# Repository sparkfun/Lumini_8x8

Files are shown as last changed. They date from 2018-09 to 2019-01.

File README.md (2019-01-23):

SparkFun LuMini 8x8 Matrix
========================================

LuMini 8x8

[*SparkFun LuMini LED matrix (COM-15047)*](https://www.sparkfun.com/products/15047)

The LuMini 8x8 Matrix is a great way to add a square of light to just about anything, or even make a screen of a custom shape. The LuMini product line uses the same LED used on our Lumenati boards, the APA102, just in a smaller, 2.0x2.0 mm package. This allows for incredibly tight pixel densities, and thus, a screen with less pixelation. 

Repository Contents
-------------------

* **/Firmware** - Example code 
* **/Hardware** - Eagle design files (.brd, .sch)
* **/Production** - Production panel files (.brd)

Documentation
--------------
* **[Hookup Guide](https://learn.sparkfun.com/tutorials/lumini-8x8-matrix-hookup-guide)** - Basic hookup guide for the LuMini 8x8 LED Matrix.

Product Versions
----------------
* [COM-15047](https://www.sparkfun.com/products/15047)- 8x8 matrix of APA102 LED's packed into a single square inch.

License Information
-------------------

This product is _**open source**_! 

Please review the LICENSE.md file for license information. 

If you have any questions or concerns on licensing, please contact techsupport@sparkfun.com.

Distributed as-is; no warranty is given.

- Your friends at SparkFun.

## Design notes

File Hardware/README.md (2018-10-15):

SparkFun <PRODUCT NAME> Design Files
=====================================

The .sch and .brd files hare are Eagle CAD schematic and PCB design files from SparkFun Electronics.
A freeware version of Eagle can be found [here](http://www.cadsoftusa.com/download-eagle/freeware/).

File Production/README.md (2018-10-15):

SparkFun <PRODUCT NAME> Production Files
=========================================

These are the production files SparkFun uses for printing PCBs.

License Information
-------------------
This product is open source! 

The hardware is released under [Creative Commons ShareAlike 4.0 International](https://creativecommons.org/licenses/by-sa/4.0/).

Please use, reuse, and modify these files as you see fit. Please maintain attribution to SparkFun Electronics and release anything derivative under the same license.

Distributed as-is; no warranty is given.

- Your friends at SparkFun.

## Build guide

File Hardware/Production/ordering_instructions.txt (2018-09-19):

panel size, 91x91mm
PCB thickness, 1.6mm
number of layers, 2
soldermask color, Unknown
silkscreen color, White
oz copper, 1oz
finish, HASL lead free
stencils, top
pcs per panel, 9

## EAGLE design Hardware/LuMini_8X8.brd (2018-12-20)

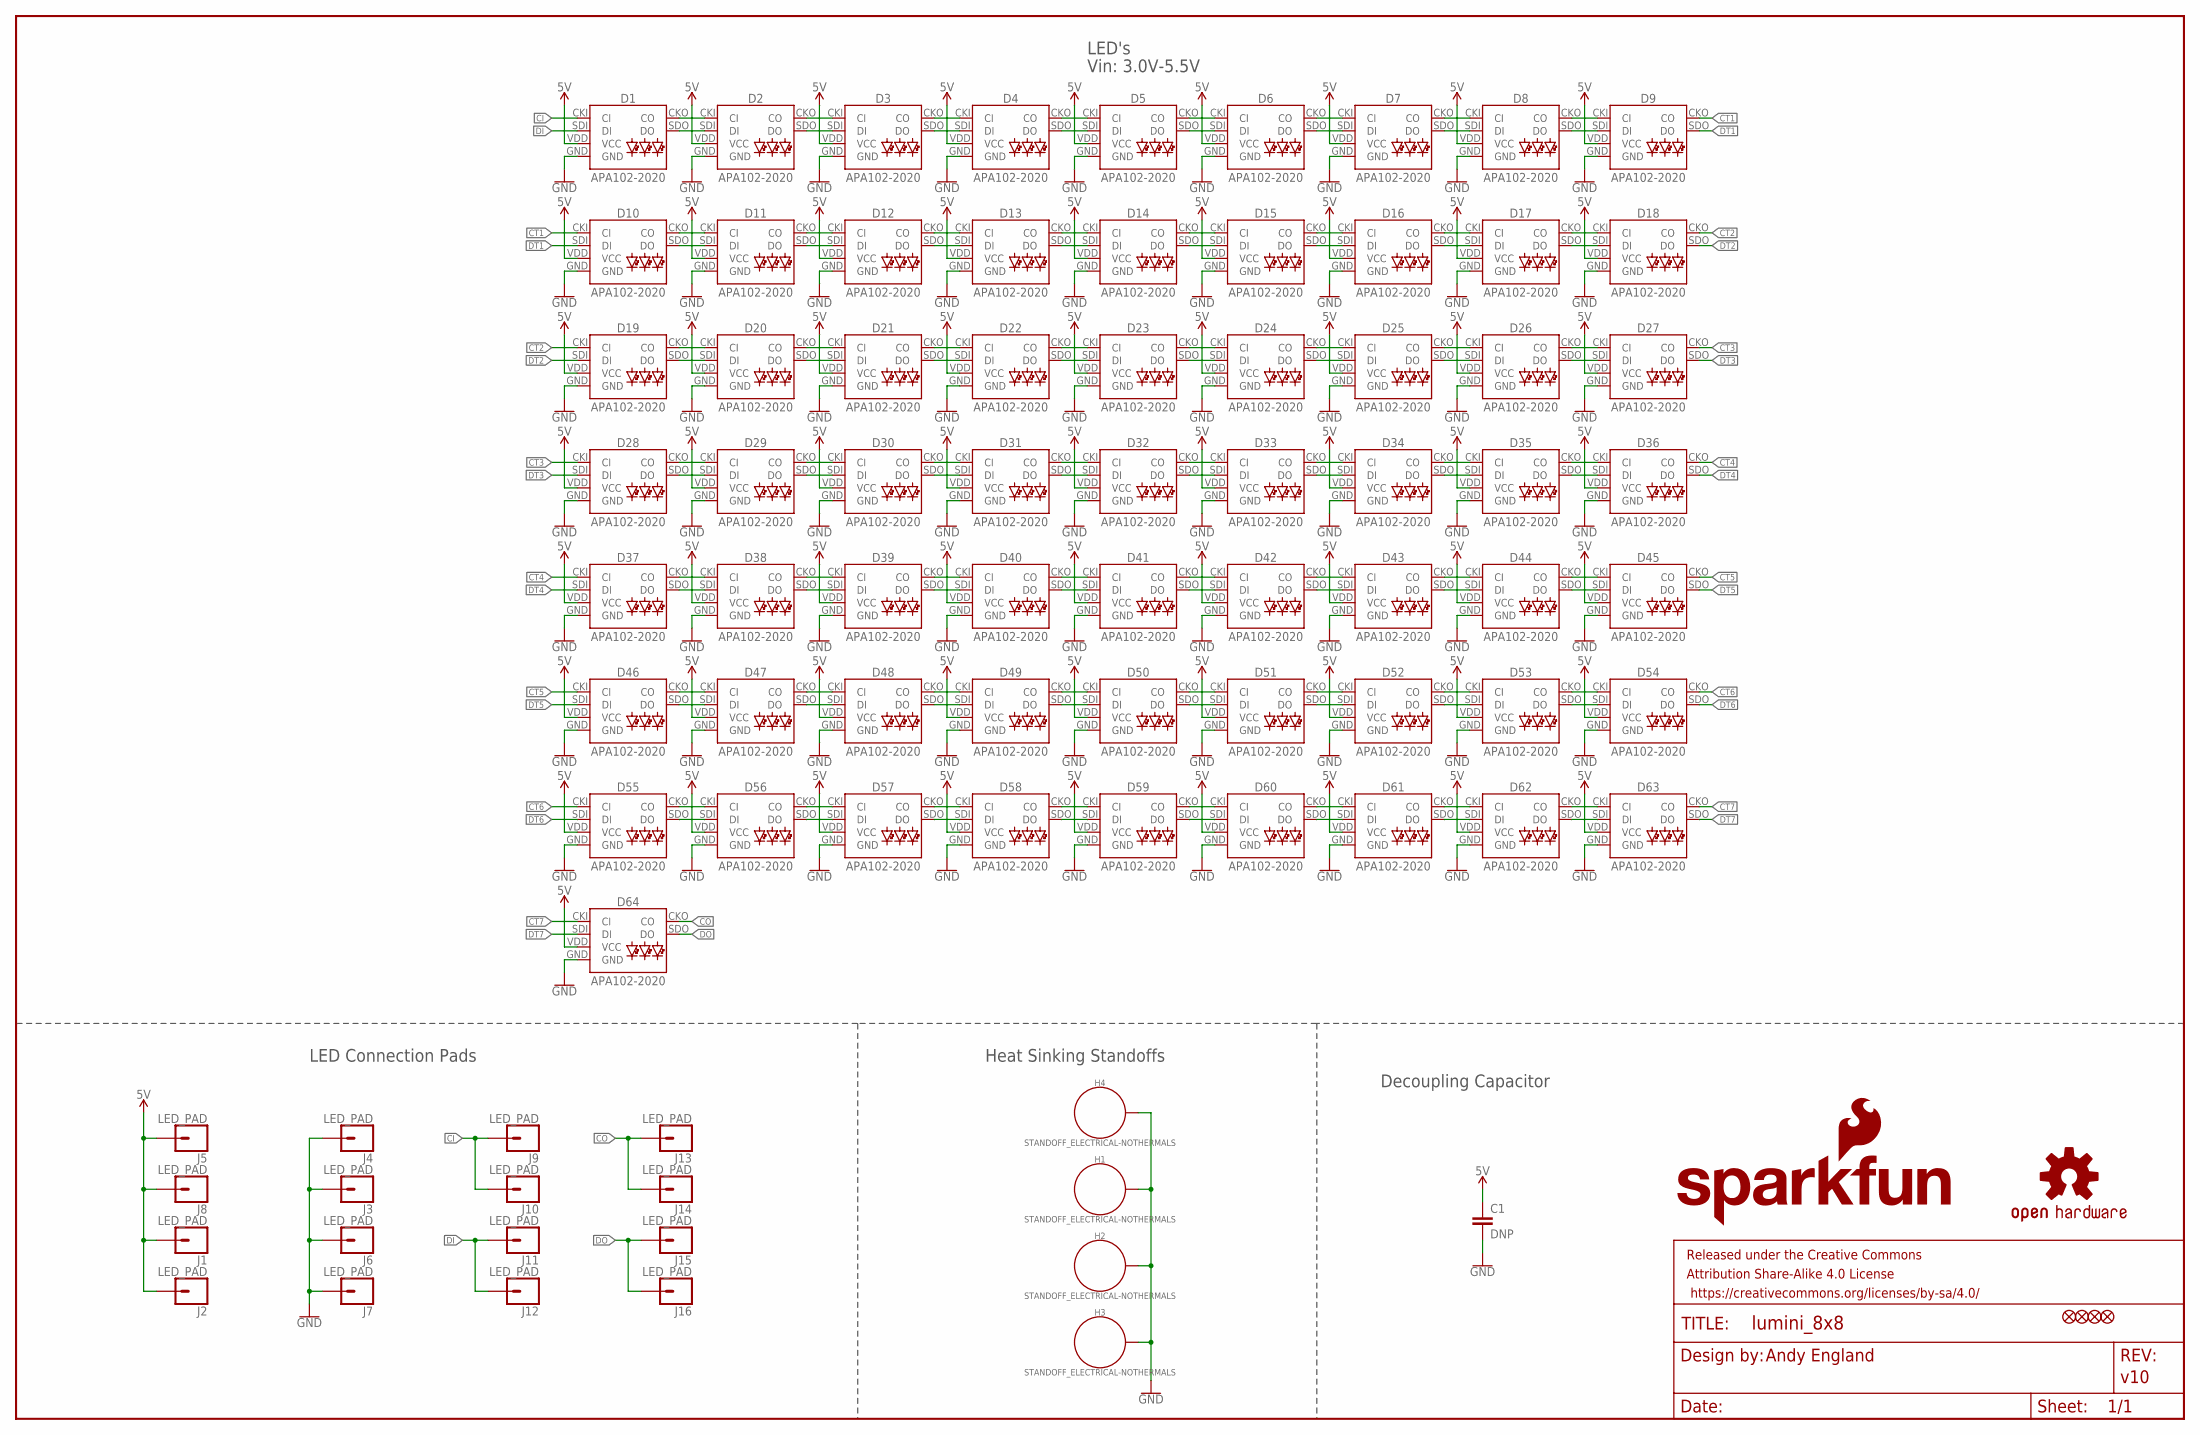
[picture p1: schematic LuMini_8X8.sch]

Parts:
C1: DNP; 1206
D1, D2, D3, D4, D5, D6, D7, D8, D9, D10, D11, D12, D13, D14, D15, D16, D17, D18, D19, D20, D21, D22, D23, D24, D25, D26, D27, D28, D29, D30, D31, D32, D33, D34, D35, D36, D37, D38, D39, D40, D41, D42, D43, D44, D45, D46, D47, D48, D49, D50, D51, D52, D53, D54, D55, D56, D57, D58, D59, D60, D61, D62, D63, D64: APA102-2020
FD1, FD2, FD3, FD4: FIDUCIALUFIDUCIAL; FIDUCIAL-MICRO
FRAME1: FRAME-LEDGER; CREATIVE_COMMONS
H1, H2, H3, H4: STANDOFF_ELECTRICAL-NOTHERMALS; STANDOFF-ELECTRICAL-NOTHERMALS
J1, J2, J3, J4, J5, J6, J7, J8, J9, J10, J11, J12, J13, J14, J15, J16: LED_PAD; CIRCULARPAD
LOGO1: SFE_LOGO_NAME_FLAME.1_INCH; SFE_LOGO_NAME_FLAME_.1
LOGO2: OSHW-LOGOS; OSHW-LOGO-S

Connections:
5V: C1.1, D1.VDD (VCC), D2.VDD (VCC), D3.VDD (VCC), D4.VDD (VCC), D5.VDD (VCC), D6.VDD (VCC), D7.VDD (VCC), D8.VDD (VCC), D9.VDD (VCC), D10.VDD (VCC), D11.VDD (VCC), D12.VDD (VCC), D13.VDD (VCC), D14.VDD (VCC), D15.VDD (VCC), D16.VDD (VCC), D17.VDD (VCC), D18.VDD (VCC), D19.VDD (VCC), D20.VDD (VCC), D21.VDD (VCC), D22.VDD (VCC), D23.VDD (VCC), D24.VDD (VCC), D25.VDD (VCC), D26.VDD (VCC), D27.VDD (VCC), D28.VDD (VCC), D29.VDD (VCC), D30.VDD (VCC), D31.VDD (VCC), D32.VDD (VCC), D33.VDD (VCC), D34.VDD (VCC), D35.VDD (VCC), D36.VDD (VCC), D37.VDD (VCC), D38.VDD (VCC), D39.VDD (VCC), D40.VDD (VCC), D41.VDD (VCC), D42.VDD (VCC), D43.VDD (VCC), D44.VDD (VCC), D45.VDD (VCC), D46.VDD (VCC), D47.VDD (VCC), D48.VDD (VCC), D49.VDD (VCC), D50.VDD (VCC), D51.VDD (VCC), D52.VDD (VCC), D53.VDD (VCC), D54.VDD (VCC), D55.VDD (VCC), D56.VDD (VCC), D57.VDD (VCC), D58.VDD (VCC), D59.VDD (VCC), D60.VDD (VCC), D61.VDD (VCC), D62.VDD (VCC), D63.VDD (VCC), D64.VDD (VCC), J1.P$1, J1.P$2, J2.P$1, J2.P$2, J5.P$1, J5.P$2, J8.P$1, J8.P$2
CI: D1.CKI (CI), J9.P$1, J9.P$2, J10.P$1, J10.P$2
CO: D64.CKO (CO), J13.P$1, J13.P$2, J14.P$1, J14.P$2
CT1: D9.CKO (CO), D10.CKI (CI)
CT2: D18.CKO (CO), D19.CKI (CI)
CT3: D27.CKO (CO), D28.CKI (CI)
CT4: D36.CKO (CO), D37.CKI (CI)
CT5: D45.CKO (CO), D46.CKI (CI)
CT6: D54.CKO (CO), D55.CKI (CI)
CT7: D63.CKO (CO), D64.CKI (CI)
DI: D1.SDI (DI), J11.P$1, J11.P$2, J12.P$1, J12.P$2
DO: D64.SDO (DO), J15.P$1, J15.P$2, J16.P$1, J16.P$2
DT1: D9.SDO (DO), D10.SDI (DI)
DT2: D18.SDO (DO), D19.SDI (DI)
DT3: D27.SDO (DO), D28.SDI (DI)
DT4: D36.SDO (DO), D37.SDI (DI)
DT5: D45.SDO (DO), D46.SDI (DI)
DT6: D54.SDO (DO), D55.SDI (DI)
DT7: D63.SDO (DO), D64.SDI (DI)
GND: C1.2, D1.GND, D2.GND, D3.GND, D4.GND, D5.GND, D6.GND, D7.GND, D8.GND, D9.GND, D10.GND, D11.GND, D12.GND, D13.GND, D14.GND, D15.GND, D16.GND, D17.GND, D18.GND, D19.GND, D20.GND, D21.GND, D22.GND, D23.GND, D24.GND, D25.GND, D26.GND, D27.GND, D28.GND, D29.GND, D30.GND, D31.GND, D32.GND, D33.GND, D34.GND, D35.GND, D36.GND, D37.GND, D38.GND, D39.GND, D40.GND, D41.GND, D42.GND, D43.GND, D44.GND, D45.GND, D46.GND, D47.GND, D48.GND, D49.GND, D50.GND, D51.GND, D52.GND, D53.GND, D54.GND, D55.GND, D56.GND, D57.GND, D58.GND, D59.GND, D60.GND, D61.GND, D62.GND, D63.GND, D64.GND, H1.P1, H2.P1, H3.P1, H4.P1, J3.P$1, J3.P$2, J4.P$1, J4.P$2, J6.P$1, J6.P$2, J7.P$1, J7.P$2
unnamed: D1.SDO (DO), D2.SDI (DI)
unnamed: D1.CKO (CO), D2.CKI (CI)
unnamed: D2.SDO (DO), D3.SDI (DI)
unnamed: D2.CKO (CO), D3.CKI (CI)
unnamed: D3.SDO (DO), D4.SDI (DI)
unnamed: D3.CKO (CO), D4.CKI (CI)
unnamed: D4.SDO (DO), D5.SDI (DI)
unnamed: D4.CKO (CO), D5.CKI (CI)
unnamed: D5.SDO (DO), D6.SDI (DI)
unnamed: D5.CKO (CO), D6.CKI (CI)
unnamed: D6.SDO (DO), D7.SDI (DI)
unnamed: D6.CKO (CO), D7.CKI (CI)
unnamed: D7.SDO (DO), D8.SDI (DI)
unnamed: D7.CKO (CO), D8.CKI (CI)
unnamed: D8.SDO (DO), D9.SDI (DI)
unnamed: D8.CKO (CO), D9.CKI (CI)
unnamed: D10.SDO (DO), D11.SDI (DI)
unnamed: D10.CKO (CO), D11.CKI (CI)
unnamed: D11.SDO (DO), D12.SDI (DI)
unnamed: D11.CKO (CO), D12.CKI (CI)
unnamed: D12.SDO (DO), D13.SDI (DI)
unnamed: D12.CKO (CO), D13.CKI (CI)
unnamed: D13.SDO (DO), D14.SDI (DI)
unnamed: D13.CKO (CO), D14.CKI (CI)
unnamed: D14.SDO (DO), D15.SDI (DI)
unnamed: D14.CKO (CO), D15.CKI (CI)
unnamed: D15.SDO (DO), D16.SDI (DI)
unnamed: D15.CKO (CO), D16.CKI (CI)
unnamed: D16.SDO (DO), D17.SDI (DI)
unnamed: D16.CKO (CO), D17.CKI (CI)
unnamed: D17.SDO (DO), D18.SDI (DI)
unnamed: D17.CKO (CO), D18.CKI (CI)
unnamed: D19.SDO (DO), D20.SDI (DI)
unnamed: D19.CKO (CO), D20.CKI (CI)
unnamed: D20.SDO (DO), D21.SDI (DI)
unnamed: D20.CKO (CO), D21.CKI (CI)
unnamed: D21.SDO (DO), D22.SDI (DI)
unnamed: D21.CKO (CO), D22.CKI (CI)
unnamed: D22.SDO (DO), D23.SDI (DI)
unnamed: D22.CKO (CO), D23.CKI (CI)
unnamed: D23.SDO (DO), D24.SDI (DI)
unnamed: D23.CKO (CO), D24.CKI (CI)
unnamed: D24.SDO (DO), D25.SDI (DI)
unnamed: D24.CKO (CO), D25.CKI (CI)
unnamed: D25.SDO (DO), D26.SDI (DI)
unnamed: D25.CKO (CO), D26.CKI (CI)
unnamed: D26.SDO (DO), D27.SDI (DI)
unnamed: D26.CKO (CO), D27.CKI (CI)
unnamed: D28.SDO (DO), D29.SDI (DI)
unnamed: D28.CKO (CO), D29.CKI (CI)
unnamed: D29.SDO (DO), D30.SDI (DI)
unnamed: D29.CKO (CO), D30.CKI (CI)
unnamed: D30.SDO (DO), D31.SDI (DI)
unnamed: D30.CKO (CO), D31.CKI (CI)
unnamed: D31.SDO (DO), D32.SDI (DI)
unnamed: D31.CKO (CO), D32.CKI (CI)
unnamed: D32.SDO (DO), D33.SDI (DI)
unnamed: D32.CKO (CO), D33.CKI (CI)
unnamed: D33.SDO (DO), D34.SDI (DI)
unnamed: D33.CKO (CO), D34.CKI (CI)
unnamed: D34.SDO (DO), D35.SDI (DI)
unnamed: D34.CKO (CO), D35.CKI (CI)
unnamed: D35.SDO (DO), D36.SDI (DI)
unnamed: D35.CKO (CO), D36.CKI (CI)
unnamed: D37.SDO (DO), D38.SDI (DI)
unnamed: D37.CKO (CO), D38.CKI (CI)
unnamed: D38.SDO (DO), D39.SDI (DI)
unnamed: D38.CKO (CO), D39.CKI (CI)
unnamed: D39.SDO (DO), D40.SDI (DI)
unnamed: D39.CKO (CO), D40.CKI (CI)
unnamed: D40.SDO (DO), D41.SDI (DI)
unnamed: D40.CKO (CO), D41.CKI (CI)
unnamed: D41.SDO (DO), D42.SDI (DI)
unnamed: D41.CKO (CO), D42.CKI (CI)
unnamed: D42.SDO (DO), D43.SDI (DI)
unnamed: D42.CKO (CO), D43.CKI (CI)
unnamed: D43.SDO (DO), D44.SDI (DI)
unnamed: D43.CKO (CO), D44.CKI (CI)
unnamed: D44.SDO (DO), D45.SDI (DI)
unnamed: D44.CKO (CO), D45.CKI (CI)
unnamed: D46.SDO (DO), D47.SDI (DI)
unnamed: D46.CKO (CO), D47.CKI (CI)
unnamed: D47.SDO (DO), D48.SDI (DI)
unnamed: D47.CKO (CO), D48.CKI (CI)
unnamed: D48.SDO (DO), D49.SDI (DI)
unnamed: D48.CKO (CO), D49.CKI (CI)
unnamed: D49.SDO (DO), D50.SDI (DI)
unnamed: D49.CKO (CO), D50.CKI (CI)
unnamed: D50.SDO (DO), D51.SDI (DI)
unnamed: D50.CKO (CO), D51.CKI (CI)
unnamed: D51.SDO (DO), D52.SDI (DI)
unnamed: D51.CKO (CO), D52.CKI (CI)
unnamed: D52.SDO (DO), D53.SDI (DI)
unnamed: D52.CKO (CO), D53.CKI (CI)
unnamed: D53.SDO (DO), D54.SDI (DI)
unnamed: D53.CKO (CO), D54.CKI (CI)
unnamed: D55.SDO (DO), D56.SDI (DI)
unnamed: D55.CKO (CO), D56.CKI (CI)
unnamed: D56.SDO (DO), D57.SDI (DI)
unnamed: D56.CKO (CO), D57.CKI (CI)
unnamed: D57.SDO (DO), D58.SDI (DI)
unnamed: D57.CKO (CO), D58.CKI (CI)
unnamed: D58.SDO (DO), D59.SDI (DI)
unnamed: D58.CKO (CO), D59.CKI (CI)
unnamed: D59.SDO (DO), D60.SDI (DI)
unnamed: D59.CKO (CO), D60.CKI (CI)
unnamed: D60.SDO (DO), D61.SDI (DI)
unnamed: D60.CKO (CO), D61.CKI (CI)
unnamed: D61.SDO (DO), D62.SDI (DI)
unnamed: D61.CKO (CO), D62.CKI (CI)
unnamed: D62.SDO (DO), D63.SDI (DI)
unnamed: D62.CKO (CO), D63.CKI (CI)

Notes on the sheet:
LED's
Heat Sinking Standoffs
Andy England
v10
LED Connection Pads
Decoupling Capacitor
Vin: 3.0V-5.5V

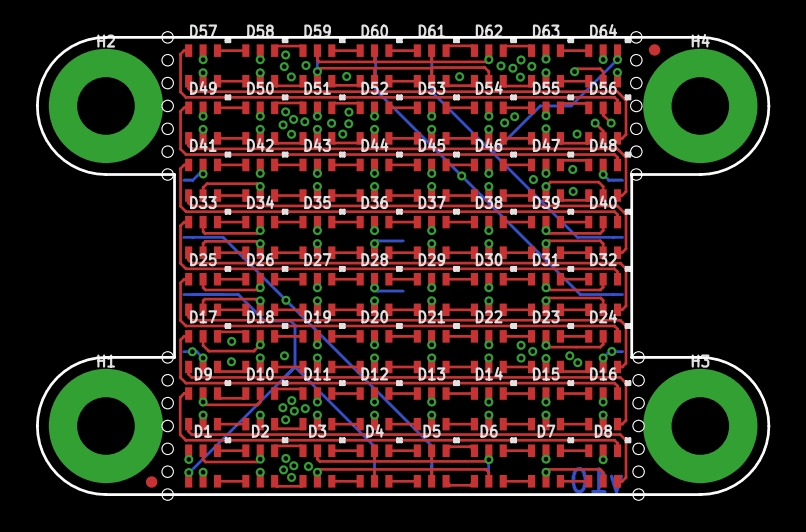
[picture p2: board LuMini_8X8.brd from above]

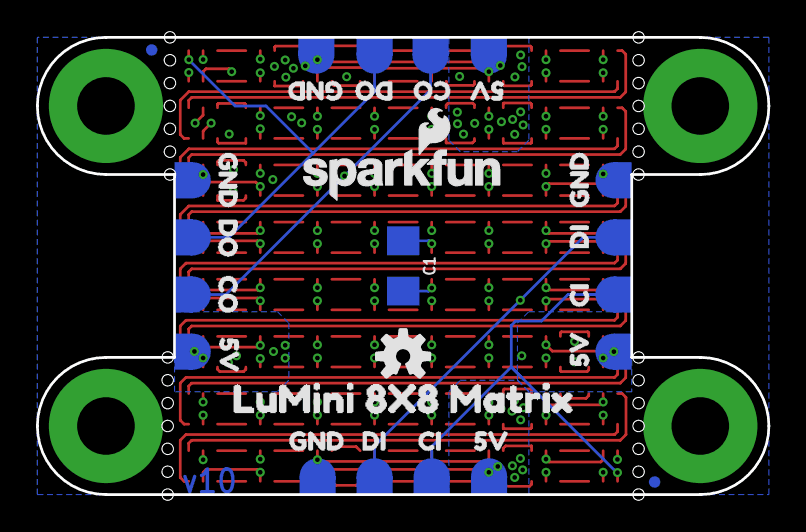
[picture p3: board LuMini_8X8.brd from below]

Board: 4 copper layers, 40.6 x 25.4 mm, 110 parts (38 on the bottom side), 132 nets.

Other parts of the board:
U$1, U$2, U$11, U$18: 5V5
U$3, U$12: CI1
U$4, U$17: CO3
U$5, U$13: DI2
U$6, U$16: DO4
U$7, U$8, U$14, U$15: GND6
U$9: LUMINI_8X8_MATRIX0
U$10: ORDERING_INSTRUCTIONS

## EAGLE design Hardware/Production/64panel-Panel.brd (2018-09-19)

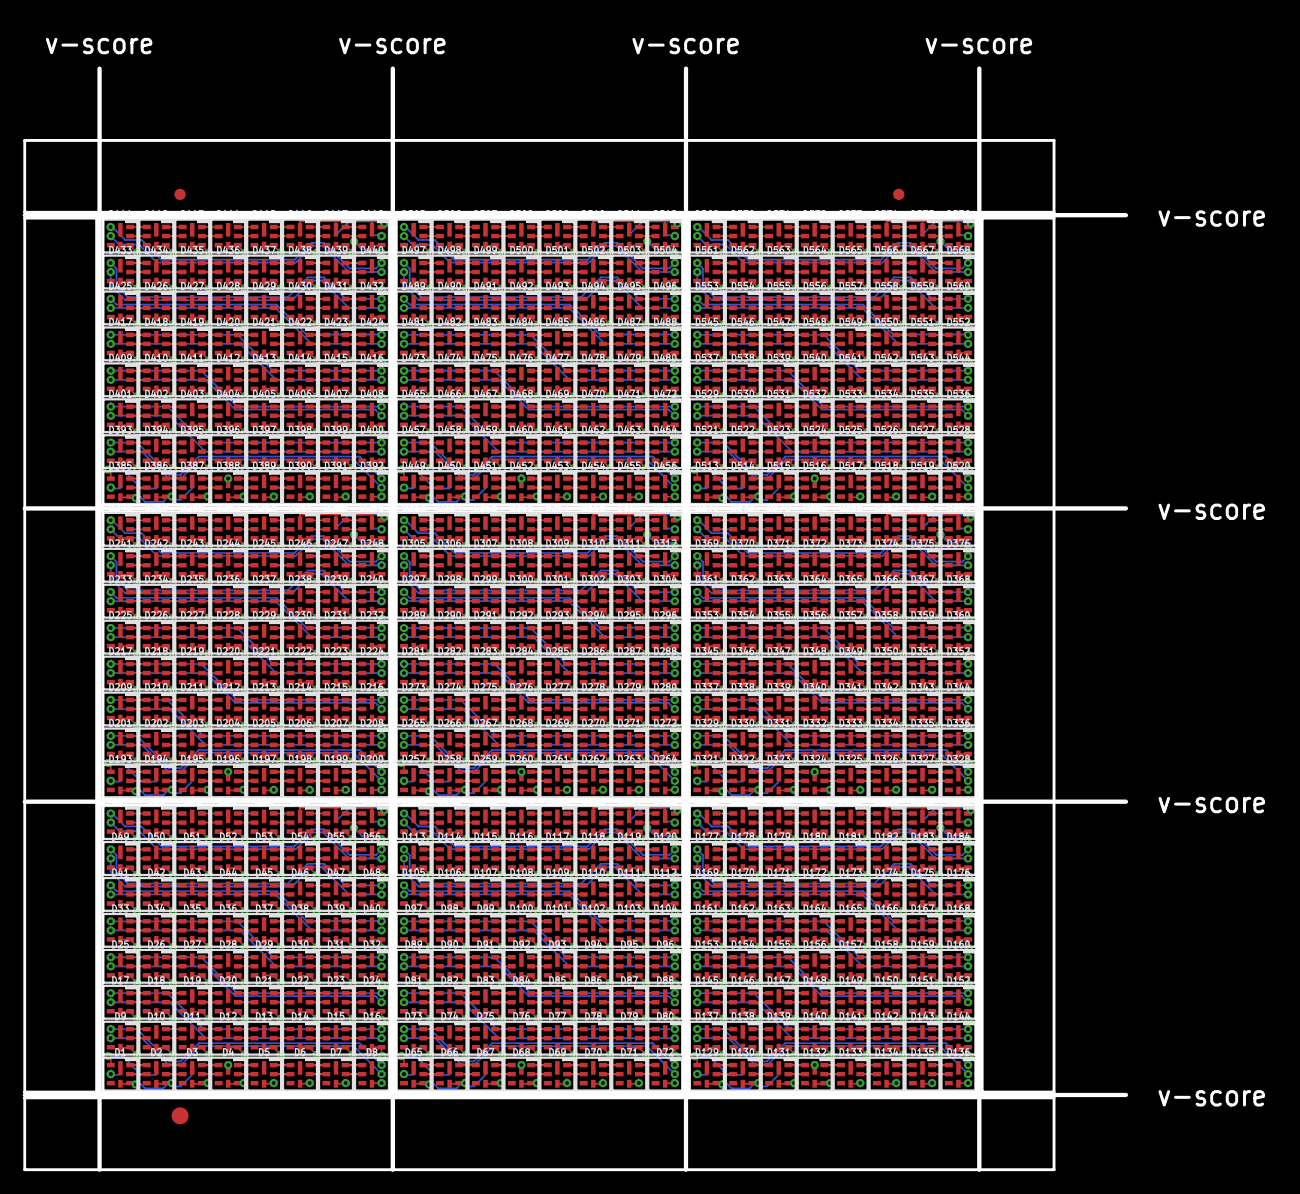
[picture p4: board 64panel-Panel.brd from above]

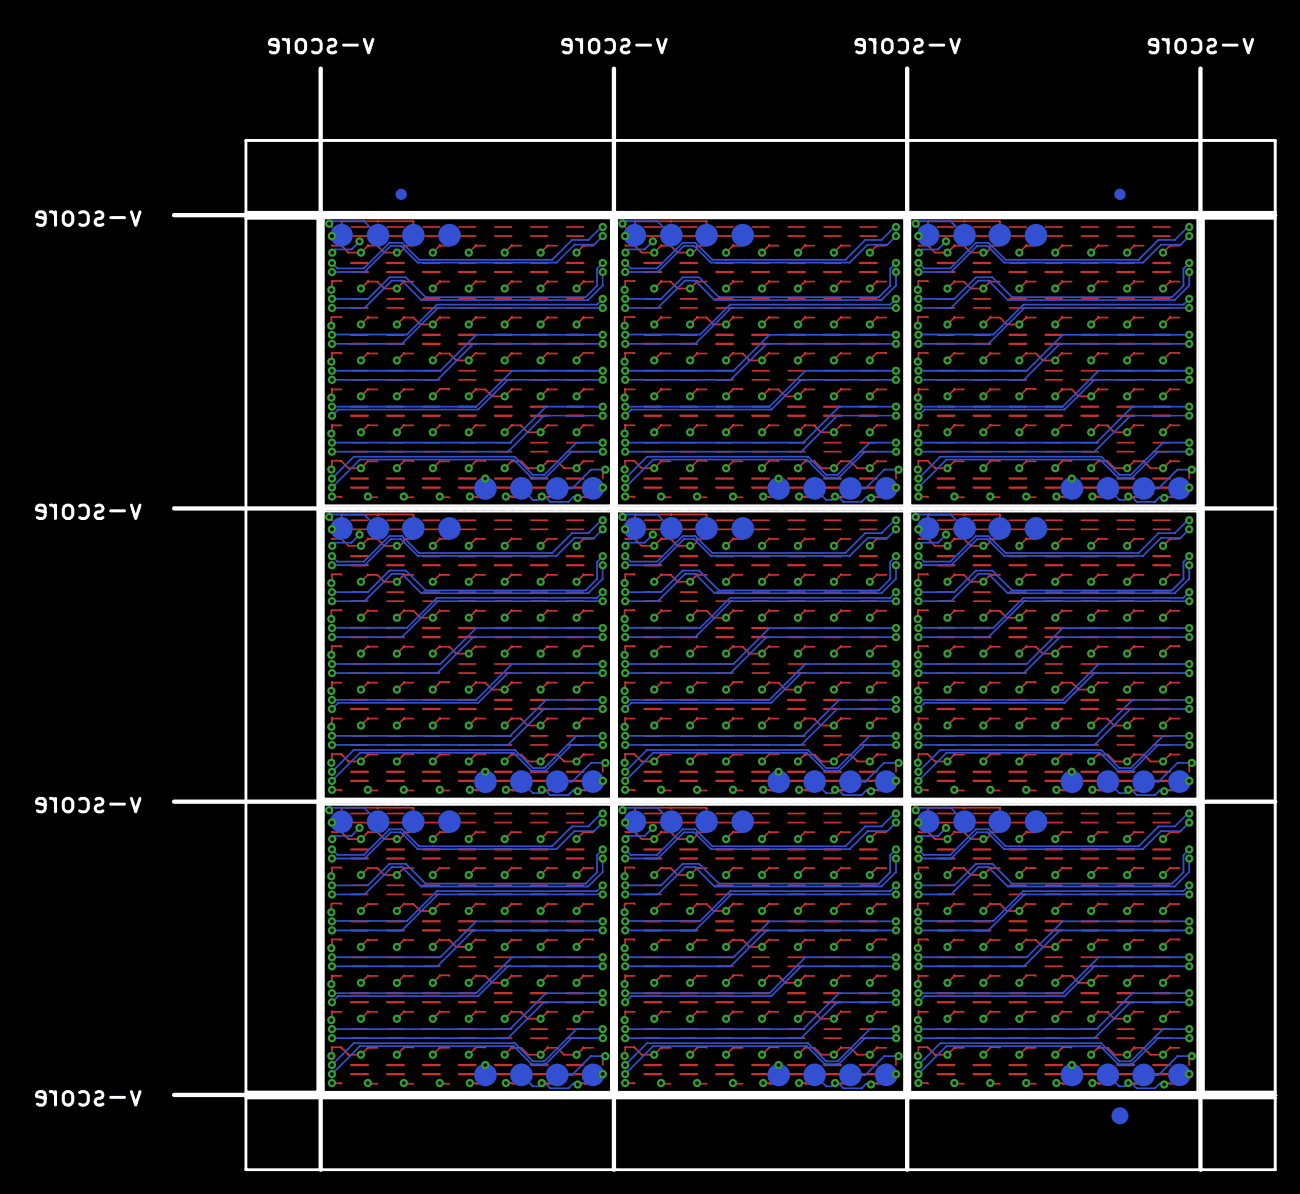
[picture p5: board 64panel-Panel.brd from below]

Board: 2 copper layers, 97.3 x 97.3 mm, 654 parts (75 on the bottom side), 1188 nets.

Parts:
D1, D2, D3, D4, D5, D6, D7, D8, D9, D10, D11, D12, D13, D14, D15, D16, D17, D18, D19, D20, D21, D22, D23, D24, D25, D26, D27, D28, D29, D30, D31, D32, D33, D34, D35, D36, D37, D38, D39, D40, D41, D42, D43, D44, D45, D46, D47, D48, D49, D50, D51, D52, D53, D54, D55, D56, D57, D58, D59, D60, D61, D62, D63, D64, D65, D66, D67, D68, D69, D70, D71, D72, D73, D74, D75, D76, D77, D78, D79, D80, D81, D82, D83, D84, D85, D86, D87, D88, D89, D90, D91, D92, D93, D94, D95, D96, D97, D98, D99, D100, D101, D102, D103, D104, D105, D106, D107, D108, D109, D110, D111, D112, D113, D114, D115, D116, D117, D118, D119, D120, D121, D122, D123, D124, D125, D126, D127, D128, D129, D130, D131, D132, D133, D134, D135, D136, D137, D138, D139, D140, D141, D142, D143, D144, D145, D146, D147, D148, D149, D150, D151, D152, D153, D154, D155, D156, D157, D158, D159, D160, D161, D162, D163, D164, D165, D166, D167, D168, D169, D170, D171, D172, D173, D174, D175, D176, D177, D178, D179, D180, D181, D182, D183, D184, D185, D186, D187, D188, D189, D190, D191, D192, D193, D194, D195, D196, D197, D198, D199, D200, D201, D202, D203, D204, D205, D206, D207, D208, D209, D210, D211, D212, D213, D214, D215, D216, D217, D218, D219, D220, D221, D222, D223, D224, D225, D226, D227, D228, D229, D230, D231, D232, D233, D234, D235, D236, D237, D238, D239, D240, D241, D242, D243, D244, D245, D246, D247, D248, D249, D250, D251, D252, D253, D254, D255, D256, D257, D258, D259, D260, D261, D262, D263, D264, D265, D266, D267, D268, D269, D270, D271, D272, D273, D274, D275, D276, D277, D278, D279, D280, D281, D282, D283, D284, D285, D286, D287, D288, D289, D290, D291, D292, D293, D294, D295, D296, D297, D298, D299, D300, D301, D302, D303, D304, D305, D306, D307, D308, D309, D310, D311, D312, D313, D314, D315, D316, D317, D318, D319, D320, D321, D322, D323, D324, D325, D326, D327, D328, D329, D330, D331, D332, D333, D334, D335, D336, D337, D338, D339, D340, D341, D342, D343, D344, D345, D346, D347, D348, D349, D350, D351, D352, D353, D354, D355, D356, D357, D358, D359, D360, D361, D362, D363, D364, D365, D366, D367, D368, D369, D370, D371, D372, D373, D374, D375, D376, D377, D378, D379, D380, D381, D382, D383, D384, D385, D386, D387, D388, D389, D390, D391, D392, D393, D394, D395, D396, D397, D398, D399, D400, D401, D402, D403, D404, D405, D406, D407, D408, D409, D410, D411, D412, D413, D414, D415, D416, D417, D418, D419, D420, D421, D422, D423, D424, D425, D426, D427, D428, D429, D430, D431, D432, D433, D434, D435, D436, D437, D438, D439, D440, D441, D442, D443, D444, D445, D446, D447, D448, D449, D450, D451, D452, D453, D454, D455, D456, D457, D458, D459, D460, D461, D462, D463, D464, D465, D466, D467, D468, D469, D470, D471, D472, D473, D474, D475, D476, D477, D478, D479, D480, D481, D482, D483, D484, D485, D486, D487, D488, D489, D490, D491, D492, D493, D494, D495, D496, D497, D498, D499, D500, D501, D502, D503, D504, D505, D506, D507, D508, D509, D510, D511, D512, D513, D514, D515, D516, D517, D518, D519, D520, D521, D522, D523, D524, D525, D526, D527, D528, D529, D530, D531, D532, D533, D534, D535, D536, D537, D538, D539, D540, D541, D542, D543, D544, D545, D546, D547, D548, D549, D550, D551, D552, D553, D554, D555, D556, D557, D558, D559, D560, D561, D562, D563, D564, D565, D566, D567, D568, D569, D570, D571, D572, D573, D574, D575, D576: APA1022020; APA102-2020
E$1, E$2, E$3, E$4: FIDUCIAL-1X2
E$5, E$6: FIDUCIAL-1.5X3
J1, J2, J3, J4, J5, J6, J7, J8, J9, J10, J11, J12, J13, J14, J15, J16, J17, J18, J19, J20, J21, J22, J23, J24, J25, J26, J27, J28, J29, J30, J31, J32, J33, J34, J35, J36, J37, J38, J39, J40, J41, J42, J43, J44, J45, J46, J47, J48, J49, J50, J51, J52, J53, J54, J55, J56, J57, J58, J59, J60, J61, J62, J63, J64, J65, J66, J67, J68, J69, J70, J71, J72: LED_PADCIRCULARPAD; CIRCULARPAD

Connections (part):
5V: D1.VDD, D1.VDDPAD, D2.VDD, D2.VDDPAD, D3.VDD, D3.VDDPAD, D4.VDD, D4.VDDPAD, D5.VDD, D5.VDDPAD, D6.VDD, D6.VDDPAD, D7.VDD, D7.VDDPAD, D8.VDD, D8.VDDPAD, D9.VDD, D9.VDDPAD, D10.VDD, D10.VDDPAD, D11.VDD, D11.VDDPAD, D12.VDD, D12.VDDPAD, D13.VDD, D13.VDDPAD, D14.VDD, D14.VDDPAD, D15.VDD, D15.VDDPAD, D16.VDD, D16.VDDPAD, D17.VDD, D17.VDDPAD, D18.VDD, D18.VDDPAD, D19.VDD, D19.VDDPAD, D20.VDD, D20.VDDPAD, D21.VDD, D21.VDDPAD, D22.VDD, D22.VDDPAD, D23.VDD, D23.VDDPAD, D24.VDD, D24.VDDPAD, D25.VDD, D25.VDDPAD, D26.VDD, D26.VDDPAD, D27.VDD, D27.VDDPAD, D28.VDD, D28.VDDPAD, D29.VDD, D29.VDDPAD, D30.VDD, D30.VDDPAD, D31.VDD, D31.VDDPAD, D32.VDD, D32.VDDPAD, D33.VDD, D33.VDDPAD, D34.VDD, D34.VDDPAD, D35.VDD, D35.VDDPAD, D36.VDD, D36.VDDPAD, D37.VDD, D37.VDDPAD, D38.VDD, D38.VDDPAD, D39.VDD, D39.VDDPAD, D40.VDD, D40.VDDPAD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
5V1: D65.VDD, D65.VDDPAD, D66.VDD, D66.VDDPAD, D67.VDD, D67.VDDPAD, D68.VDD, D68.VDDPAD, D69.VDD, D69.VDDPAD, D70.VDD, D70.VDDPAD, D71.VDD, D71.VDDPAD, D72.VDD, D72.VDDPAD, D73.VDD, D73.VDDPAD, D74.VDD, D74.VDDPAD, D75.VDD, D75.VDDPAD, D76.VDD, D76.VDDPAD, D77.VDD, D77.VDDPAD, D78.VDD, D78.VDDPAD, D79.VDD, D79.VDDPAD, D80.VDD, D80.VDDPAD, D81.VDD, D81.VDDPAD, D82.VDD, D82.VDDPAD, D83.VDD, D83.VDDPAD, D84.VDD, D84.VDDPAD, D85.VDD, D85.VDDPAD, D86.VDD, D86.VDDPAD, D87.VDD, D87.VDDPAD, D88.VDD, D88.VDDPAD, D89.VDD, D89.VDDPAD, D90.VDD, D90.VDDPAD, D91.VDD, D91.VDDPAD, D92.VDD, D92.VDDPAD, D93.VDD, D93.VDDPAD, D94.VDD, D94.VDDPAD, D95.VDD, D95.VDDPAD, D96.VDD, D96.VDDPAD, D97.VDD, D97.VDDPAD, D98.VDD, D98.VDDPAD, D99.VDD, D99.VDDPAD, D100.VDD, D100.VDDPAD, D101.VDD, D101.VDDPAD, D102.VDD, D102.VDDPAD, D103.VDD, D103.VDDPAD, D104.VDD, D104.VDDPAD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
5V2: D129.VDD, D129.VDDPAD, D130.VDD, D130.VDDPAD, D131.VDD, D131.VDDPAD, D132.VDD, D132.VDDPAD, D133.VDD, D133.VDDPAD, D134.VDD, D134.VDDPAD, D135.VDD, D135.VDDPAD, D136.VDD, D136.VDDPAD, D137.VDD, D137.VDDPAD, D138.VDD, D138.VDDPAD, D139.VDD, D139.VDDPAD, D140.VDD, D140.VDDPAD, D141.VDD, D141.VDDPAD, D142.VDD, D142.VDDPAD, D143.VDD, D143.VDDPAD, D144.VDD, D144.VDDPAD, D145.VDD, D145.VDDPAD, D146.VDD, D146.VDDPAD, D147.VDD, D147.VDDPAD, D148.VDD, D148.VDDPAD, D149.VDD, D149.VDDPAD, D150.VDD, D150.VDDPAD, D151.VDD, D151.VDDPAD, D152.VDD, D152.VDDPAD, D153.VDD, D153.VDDPAD, D154.VDD, D154.VDDPAD, D155.VDD, D155.VDDPAD, D156.VDD, D156.VDDPAD, D157.VDD, D157.VDDPAD, D158.VDD, D158.VDDPAD, D159.VDD, D159.VDDPAD, D160.VDD, D160.VDDPAD, D161.VDD, D161.VDDPAD, D162.VDD, D162.VDDPAD, D163.VDD, D163.VDDPAD, D164.VDD, D164.VDDPAD, D165.VDD, D165.VDDPAD, D166.VDD, D166.VDDPAD, D167.VDD, D167.VDDPAD, D168.VDD, D168.VDDPAD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
5V3: D193.VDD, D193.VDDPAD, D194.VDD, D194.VDDPAD, D195.VDD, D195.VDDPAD, D196.VDD, D196.VDDPAD, D197.VDD, D197.VDDPAD, D198.VDD, D198.VDDPAD, D199.VDD, D199.VDDPAD, D200.VDD, D200.VDDPAD, D201.VDD, D201.VDDPAD, D202.VDD, D202.VDDPAD, D203.VDD, D203.VDDPAD, D204.VDD, D204.VDDPAD, D205.VDD, D205.VDDPAD, D206.VDD, D206.VDDPAD, D207.VDD, D207.VDDPAD, D208.VDD, D208.VDDPAD, D209.VDD, D209.VDDPAD, D210.VDD, D210.VDDPAD, D211.VDD, D211.VDDPAD, D212.VDD, D212.VDDPAD, D213.VDD, D213.VDDPAD, D214.VDD, D214.VDDPAD, D215.VDD, D215.VDDPAD, D216.VDD, D216.VDDPAD, D217.VDD, D217.VDDPAD, D218.VDD, D218.VDDPAD, D219.VDD, D219.VDDPAD, D220.VDD, D220.VDDPAD, D221.VDD, D221.VDDPAD, D222.VDD, D222.VDDPAD, D223.VDD, D223.VDDPAD, D224.VDD, D224.VDDPAD, D225.VDD, D225.VDDPAD, D226.VDD, D226.VDDPAD, D227.VDD, D227.VDDPAD, D228.VDD, D228.VDDPAD, D229.VDD, D229.VDDPAD, D230.VDD, D230.VDDPAD, D231.VDD, D231.VDDPAD, D232.VDD, D232.VDDPAD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
5V4: D257.VDD, D257.VDDPAD, D258.VDD, D258.VDDPAD, D259.VDD, D259.VDDPAD, D260.VDD, D260.VDDPAD, D261.VDD, D261.VDDPAD, D262.VDD, D262.VDDPAD, D263.VDD, D263.VDDPAD, D264.VDD, D264.VDDPAD, D265.VDD, D265.VDDPAD, D266.VDD, D266.VDDPAD, D267.VDD, D267.VDDPAD, D268.VDD, D268.VDDPAD, D269.VDD, D269.VDDPAD, D270.VDD, D270.VDDPAD, D271.VDD, D271.VDDPAD, D272.VDD, D272.VDDPAD, D273.VDD, D273.VDDPAD, D274.VDD, D274.VDDPAD, D275.VDD, D275.VDDPAD, D276.VDD, D276.VDDPAD, D277.VDD, D277.VDDPAD, D278.VDD, D278.VDDPAD, D279.VDD, D279.VDDPAD, D280.VDD, D280.VDDPAD, D281.VDD, D281.VDDPAD, D282.VDD, D282.VDDPAD, D283.VDD, D283.VDDPAD, D284.VDD, D284.VDDPAD, D285.VDD, D285.VDDPAD, D286.VDD, D286.VDDPAD, D287.VDD, D287.VDDPAD, D288.VDD, D288.VDDPAD, D289.VDD, D289.VDDPAD, D290.VDD, D290.VDDPAD, D291.VDD, D291.VDDPAD, D292.VDD, D292.VDDPAD, D293.VDD, D293.VDDPAD, D294.VDD, D294.VDDPAD, D295.VDD, D295.VDDPAD, D296.VDD, D296.VDDPAD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
5V5: D321.VDD, D321.VDDPAD, D322.VDD, D322.VDDPAD, D323.VDD, D323.VDDPAD, D324.VDD, D324.VDDPAD, D325.VDD, D325.VDDPAD, D326.VDD, D326.VDDPAD, D327.VDD, D327.VDDPAD, D328.VDD, D328.VDDPAD, D329.VDD, D329.VDDPAD, D330.VDD, D330.VDDPAD, D331.VDD, D331.VDDPAD, D332.VDD, D332.VDDPAD, D333.VDD, D333.VDDPAD, D334.VDD, D334.VDDPAD, D335.VDD, D335.VDDPAD, D336.VDD, D336.VDDPAD, D337.VDD, D337.VDDPAD, D338.VDD, D338.VDDPAD, D339.VDD, D339.VDDPAD, D340.VDD, D340.VDDPAD, D341.VDD, D341.VDDPAD, D342.VDD, D342.VDDPAD, D343.VDD, D343.VDDPAD, D344.VDD, D344.VDDPAD, D345.VDD, D345.VDDPAD, D346.VDD, D346.VDDPAD, D347.VDD, D347.VDDPAD, D348.VDD, D348.VDDPAD, D349.VDD, D349.VDDPAD, D350.VDD, D350.VDDPAD, D351.VDD, D351.VDDPAD, D352.VDD, D352.VDDPAD, D353.VDD, D353.VDDPAD, D354.VDD, D354.VDDPAD, D355.VDD, D355.VDDPAD, D356.VDD, D356.VDDPAD, D357.VDD, D357.VDDPAD, D358.VDD, D358.VDDPAD, D359.VDD, D359.VDDPAD, D360.VDD, D360.VDDPAD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
5V6: D385.VDD, D385.VDDPAD, D386.VDD, D386.VDDPAD, D387.VDD, D387.VDDPAD, D388.VDD, D388.VDDPAD, D389.VDD, D389.VDDPAD, D390.VDD, D390.VDDPAD, D391.VDD, D391.VDDPAD, D392.VDD, D392.VDDPAD, D393.VDD, D393.VDDPAD, D394.VDD, D394.VDDPAD, D395.VDD, D395.VDDPAD, D396.VDD, D396.VDDPAD, D397.VDD, D397.VDDPAD, D398.VDD, D398.VDDPAD, D399.VDD, D399.VDDPAD, D400.VDD, D400.VDDPAD, D401.VDD, D401.VDDPAD, D402.VDD, D402.VDDPAD, D403.VDD, D403.VDDPAD, D404.VDD, D404.VDDPAD, D405.VDD, D405.VDDPAD, D406.VDD, D406.VDDPAD, D407.VDD, D407.VDDPAD, D408.VDD, D408.VDDPAD, D409.VDD, D409.VDDPAD, D410.VDD, D410.VDDPAD, D411.VDD, D411.VDDPAD, D412.VDD, D412.VDDPAD, D413.VDD, D413.VDDPAD, D414.VDD, D414.VDDPAD, D415.VDD, D415.VDDPAD, D416.VDD, D416.VDDPAD, D417.VDD, D417.VDDPAD, D418.VDD, D418.VDDPAD, D419.VDD, D419.VDDPAD, D420.VDD, D420.VDDPAD, D421.VDD, D421.VDDPAD, D422.VDD, D422.VDDPAD, D423.VDD, D423.VDDPAD, D424.VDD, D424.VDDPAD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
5V7: D449.VDD, D449.VDDPAD, D450.VDD, D450.VDDPAD, D451.VDD, D451.VDDPAD, D452.VDD, D452.VDDPAD, D453.VDD, D453.VDDPAD, D454.VDD, D454.VDDPAD, D455.VDD, D455.VDDPAD, D456.VDD, D456.VDDPAD, D457.VDD, D457.VDDPAD, D458.VDD, D458.VDDPAD, D459.VDD, D459.VDDPAD, D460.VDD, D460.VDDPAD, D461.VDD, D461.VDDPAD, D462.VDD, D462.VDDPAD, D463.VDD, D463.VDDPAD, D464.VDD, D464.VDDPAD, D465.VDD, D465.VDDPAD, D466.VDD, D466.VDDPAD, D467.VDD, D467.VDDPAD, D468.VDD, D468.VDDPAD, D469.VDD, D469.VDDPAD, D470.VDD, D470.VDDPAD, D471.VDD, D471.VDDPAD, D472.VDD, D472.VDDPAD, D473.VDD, D473.VDDPAD, D474.VDD, D474.VDDPAD, D475.VDD, D475.VDDPAD, D476.VDD, D476.VDDPAD, D477.VDD, D477.VDDPAD, D478.VDD, D478.VDDPAD, D479.VDD, D479.VDDPAD, D480.VDD, D480.VDDPAD, D481.VDD, D481.VDDPAD, D482.VDD, D482.VDDPAD, D483.VDD, D483.VDDPAD, D484.VDD, D484.VDDPAD, D485.VDD, D485.VDDPAD, D486.VDD, D486.VDDPAD, D487.VDD, D487.VDDPAD, D488.VDD, D488.VDDPAD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
5V8: D513.VDD, D513.VDDPAD, D514.VDD, D514.VDDPAD, D515.VDD, D515.VDDPAD, D516.VDD, D516.VDDPAD, D517.VDD, D517.VDDPAD, D518.VDD, D518.VDDPAD, D519.VDD, D519.VDDPAD, D520.VDD, D520.VDDPAD, D521.VDD, D521.VDDPAD, D522.VDD, D522.VDDPAD, D523.VDD, D523.VDDPAD, D524.VDD, D524.VDDPAD, D525.VDD, D525.VDDPAD, D526.VDD, D526.VDDPAD, D527.VDD, D527.VDDPAD, D528.VDD, D528.VDDPAD, D529.VDD, D529.VDDPAD, D530.VDD, D530.VDDPAD, D531.VDD, D531.VDDPAD, D532.VDD, D532.VDDPAD, D533.VDD, D533.VDDPAD, D534.VDD, D534.VDDPAD, D535.VDD, D535.VDDPAD, D536.VDD, D536.VDDPAD, D537.VDD, D537.VDDPAD, D538.VDD, D538.VDDPAD, D539.VDD, D539.VDDPAD, D540.VDD, D540.VDDPAD, D541.VDD, D541.VDDPAD, D542.VDD, D542.VDDPAD, D543.VDD, D543.VDDPAD, D544.VDD, D544.VDDPAD, D545.VDD, D545.VDDPAD, D546.VDD, D546.VDDPAD, D547.VDD, D547.VDDPAD, D548.VDD, D548.VDDPAD, D549.VDD, D549.VDDPAD, D550.VDD, D550.VDDPAD, D551.VDD, D551.VDDPAD, D552.VDD, D552.VDDPAD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
CI: D1.CKI, J4.P$1
CI1: D65.CKI, J12.P$1
CI2: D129.CKI, J20.P$1
CI3: D193.CKI, J28.P$1
CI4: D257.CKI, J36.P$1
CI5: D321.CKI, J44.P$1
CI6: D385.CKI, J52.P$1
CI7: D449.CKI, J60.P$1
CI8: D513.CKI, J68.P$1
CO: D64.CKO, J1.P$1
CO1: D128.CKO, J9.P$1
CO2: D192.CKO, J17.P$1
CO3: D256.CKO, J25.P$1
CO4: D320.CKO, J33.P$1
CO5: D384.CKO, J41.P$1
CO6: D448.CKO, J49.P$1
CO7: D512.CKO, J57.P$1
CO8: D576.CKO, J65.P$1
CT1: D9.CKO, D10.CKI
CT2: D18.CKO, D19.CKI
CT3: D27.CKO, D28.CKI
CT4: D36.CKO, D37.CKI
CT5: D45.CKO, D46.CKI
CT6: D54.CKO, D55.CKI
CT7: D63.CKO, D64.CKI
CT8: D127.CKO, D128.CKI
CT9: D73.CKO, D74.CKI
CT10: D82.CKO, D83.CKI
CT11: D91.CKO, D92.CKI
CT12: D100.CKO, D101.CKI
CT13: D109.CKO, D110.CKI
CT14: D118.CKO, D119.CKI
CT15: D191.CKO, D192.CKI
CT16: D137.CKO, D138.CKI
CT17: D146.CKO, D147.CKI
CT18: D155.CKO, D156.CKI
CT19: D164.CKO, D165.CKI
CT20: D173.CKO, D174.CKI
CT21: D182.CKO, D183.CKI
CT22: D255.CKO, D256.CKI
CT23: D201.CKO, D202.CKI
CT24: D210.CKO, D211.CKI
CT25: D219.CKO, D220.CKI
CT26: D228.CKO, D229.CKI
CT27: D237.CKO, D238.CKI
CT28: D246.CKO, D247.CKI
CT29: D319.CKO, D320.CKI
CT30: D265.CKO, D266.CKI
CT31: D274.CKO, D275.CKI
CT32: D283.CKO, D284.CKI
CT33: D292.CKO, D293.CKI
CT34: D301.CKO, D302.CKI
CT35: D310.CKO, D311.CKI
CT36: D383.CKO, D384.CKI
CT37: D329.CKO, D330.CKI
CT38: D338.CKO, D339.CKI
CT39: D347.CKO, D348.CKI
CT40: D356.CKO, D357.CKI
CT41: D365.CKO, D366.CKI
CT42: D374.CKO, D375.CKI
CT43: D447.CKO, D448.CKI
CT44: D393.CKO, D394.CKI
CT45: D402.CKO, D403.CKI
CT46: D411.CKO, D412.CKI
CT47: D420.CKO, D421.CKI
CT48: D429.CKO, D430.CKI
CT49: D438.CKO, D439.CKI
CT50: D511.CKO, D512.CKI
CT51: D457.CKO, D458.CKI
CT52: D466.CKO, D467.CKI
CT53: D475.CKO, D476.CKI
CT54: D484.CKO, D485.CKI
CT55: D493.CKO, D494.CKI
CT56: D502.CKO, D503.CKI
CT57: D575.CKO, D576.CKI
CT58: D521.CKO, D522.CKI
CT59: D530.CKO, D531.CKI
CT60: D539.CKO, D540.CKI
CT61: D548.CKO, D549.CKI
CT62: D557.CKO, D558.CKI
CT63: D566.CKO, D567.CKI
DI: D1.SDI, J3.P$1
DI1: D65.SDI, J11.P$1
DI2: D129.SDI, J19.P$1
DI3: D193.SDI, J27.P$1
DI4: D257.SDI, J35.P$1
DI5: D321.SDI, J43.P$1
DI6: D385.SDI, J51.P$1
DI7: D449.SDI, J59.P$1
DI8: D513.SDI, J67.P$1
DO: D64.SDO, J2.P$1
DO1: D128.SDO, J10.P$1
DO2: D192.SDO, J18.P$1
DO3: D256.SDO, J26.P$1
DO4: D320.SDO, J34.P$1
DO5: D384.SDO, J42.P$1
DO6: D448.SDO, J50.P$1
DO7: D512.SDO, J58.P$1
DO8: D576.SDO, J66.P$1
DT1: D9.SDO, D10.SDI
DT2: D18.SDO, D19.SDI
DT3: D27.SDO, D28.SDI
DT4: D36.SDO, D37.SDI
DT5: D45.SDO, D46.SDI
DT6: D54.SDO, D55.SDI
DT7: D63.SDO, D64.SDI
DT8: D127.SDO, D128.SDI
DT9: D73.SDO, D74.SDI
DT10: D82.SDO, D83.SDI
DT11: D91.SDO, D92.SDI
DT12: D100.SDO, D101.SDI
DT13: D109.SDO, D110.SDI
DT14: D118.SDO, D119.SDI
DT15: D191.SDO, D192.SDI
DT16: D137.SDO, D138.SDI
DT17: D146.SDO, D147.SDI
DT18: D155.SDO, D156.SDI
DT19: D164.SDO, D165.SDI
DT20: D173.SDO, D174.SDI
DT21: D182.SDO, D183.SDI
DT22: D255.SDO, D256.SDI
DT23: D201.SDO, D202.SDI
DT24: D210.SDO, D211.SDI
DT25: D219.SDO, D220.SDI
DT26: D228.SDO, D229.SDI
DT27: D237.SDO, D238.SDI
DT28: D246.SDO, D247.SDI
DT29: D319.SDO, D320.SDI
DT30: D265.SDO, D266.SDI
DT31: D274.SDO, D275.SDI
DT32: D283.SDO, D284.SDI
DT33: D292.SDO, D293.SDI
DT34: D301.SDO, D302.SDI
DT35: D310.SDO, D311.SDI
DT36: D383.SDO, D384.SDI
DT37: D329.SDO, D330.SDI
DT38: D338.SDO, D339.SDI
DT39: D347.SDO, D348.SDI
DT40: D356.SDO, D357.SDI
DT41: D365.SDO, D366.SDI
DT42: D374.SDO, D375.SDI
DT43: D447.SDO, D448.SDI
DT44: D393.SDO, D394.SDI
DT45: D402.SDO, D403.SDI
DT46: D411.SDO, D412.SDI
DT47: D420.SDO, D421.SDI
DT48: D429.SDO, D430.SDI
DT49: D438.SDO, D439.SDI
DT50: D511.SDO, D512.SDI
DT51: D457.SDO, D458.SDI
DT52: D466.SDO, D467.SDI
DT53: D475.SDO, D476.SDI
DT54: D484.SDO, D485.SDI
DT55: D493.SDO, D494.SDI
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

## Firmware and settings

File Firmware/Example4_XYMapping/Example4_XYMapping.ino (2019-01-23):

#include <FastLED.h>

//How many matrices are you using?
#define NUM_MATRICES 4
#define NUM_LEDS 64 * NUM_MATRICES

// The LuMini matrices need two data pins connected
#define DATA_PIN 16
#define CLOCK_PIN 17

// Define the array of leds
CRGB matrix[NUM_LEDS];

//The Height and Width of each individual matrix
int individualMatrixWidth = 8;
int individualMatrixHeight = 8;

const int moduleHeight = 2; //The Height of our display, measured in numbers of LuMini matrices
const int moduleWidth = 2; //The Width of our display, measured in numbers of LuMini matrices

//The following matrix represents our entire LED display, with the number that each module is in the chain. My data flows in to the bottom left matrix (matrix 0 in my chain),
//then it goes right to the bottom right matrix (matrix 1 in my chain) then up to the top right matrix (matrix 2) then to the remaining matrix 3
//The below table should have identical matrix numbers/positions as that of the multi-matrix display
int matrixMap[moduleHeight][moduleWidth] = {
  {3, 2},
  {0, 1}
};


//Not every matrix will have the same orientation (matrices may be rotated 90, 180, or 270 degrees from each other)
//Properly oriented matrices will show a line of color wiping from left to right if their orientation is 0
//If a matrix shows any of the following color wipes, change it's orientation to the corresponding number:
//Top to Bottom: 1
//Right to Left: 2
//Bottom to Top: 3
int orientation[moduleHeight * moduleWidth] = { 0, 0, 0, 1 };

void fadeAll(uint8_t scale = 250)
{
  for (int i = 0; i < NUM_LEDS; i++)
  {
    matrix[i].nscale8(scale);
  }
}

uint16_t XY( uint16_t x, uint16_t y)
{
  uint16_t i;
  uint8_t matrixNum = matrixMap[(moduleHeight - 1) - (y / individualMatrixHeight)][x / individualMatrixWidth]; //Calculates which matrix we are on using the matrix map
  uint8_t relativeX; //x position relative to the origin of the current matrix
  uint8_t relativeY; //y position relative to the origin of the current matrix
  switch (orientation[matrixNum])//Transposes our values based on orientation
  {
    case 0:
      relativeX = x % individualMatrixWidth;
      relativeY = y % individualMatrixHeight;
      break;
    case 1:
      relativeX = 7 - (y % individualMatrixWidth);
      relativeY = x % individualMatrixHeight;
      break;
    case 2:
      relativeX = 7 - (x % individualMatrixWidth);
      relativeY = y % individualMatrixHeight;
      break;
    case 3:
      relativeX = y % individualMatrixWidth;
      relativeY = x % individualMatrixHeight;
      break;
  }
  i = (relativeY * individualMatrixWidth) + relativeX; //Calculates where we are on a matrix
  i += matrixNum * individualMatrixWidth * individualMatrixHeight; //Adds on offset based on which matrix we're on in the chain.
  return i;
}

void setup() {
  Serial.begin(115200);  
  LEDS.addLeds<APA102, DATA_PIN, CLOCK_PIN, BGR, DATA_RATE_MHZ(1)>(matrix, NUM_LEDS);
  LEDS.setBrightness(32);
}

void loop() {
  static uint8_t hue = 0;
  //Draw vertical bars from left to right
  for (int x = 0; x < individualMatrixWidth * moduleWidth; x++)
  {
    for (int y = 0; y < individualMatrixHeight * moduleHeight; y++)
    {
      // Set the i'th led to the current hue
      matrix[XY(x, y)] = CHSV(hue, 150, 255); //display the current hue, then increment it.
    }
    FastLED.show();
    delay(20);
    fadeAll(127);//Reduce the brightness of all LEDs so our LED's fade off with every frame.
    hue++;
  }
}

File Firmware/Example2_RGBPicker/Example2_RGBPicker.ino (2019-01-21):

#include <FastLED.h>

// How many leds in your chain? Change the value of NUM_BOARDS depending on your setup
#define NUM_BOARDS 1
#define NUM_LEDS 64 * NUM_BOARDS //64 LED's per board

//Data and Clock Pins
#define DATA_PIN 16
#define CLOCK_PIN 17

CRGB color;
char colorToEdit;

// Define the array of leds
CRGB matrix[NUM_LEDS];

void setup() {
  Serial.begin(115200);
  Serial.println("resetting");
  LEDS.addLeds<APA102, DATA_PIN, CLOCK_PIN, BGR>(matrix, NUM_LEDS);
  LEDS.setBrightness(32);

  //Display our current color data
  Serial.print("Red Value: ");
  Serial.println(color[0]);
  Serial.print("Green Value: ");
  Serial.println(color[1]);
  Serial.print("Blue Value: ");
  Serial.println(color[2]);
  Serial.println();
}

void loop()
{
  if (Serial.available()) //Check to see if we have new Serial data.
  {
    colorToEdit = Serial.read();
    switch (colorToEdit)
    {
      case 'R':
      case 'r':
        color[0] = Serial.parseInt();
        break;
      case 'G':
      case 'g':
        color[1] = Serial.parseInt();
        break;
      case 'B':
      case 'b':
        color[2] = Serial.parseInt();
        break;
    }
    //Display our current color data
    Serial.print("Red Value: ");
    Serial.println(color[0]);
    Serial.print("Green Value: ");
    Serial.println(color[1]);
    Serial.print("Blue Value: ");
    Serial.println(color[2]);
    Serial.println();
    for (int i = 0; i < NUM_LEDS; i++)
    {
      matrix[i] = color;
      FastLED.show();
      delay(10);
    }
  }
}

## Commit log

2018-09-19 finished laying out board, ordered panels
    [64panel-Panel.GBL, 64panel-Panel.GBO, 64panel-Panel.GBS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]
2018-10-15 changing to 6-pin
    [64panel.brd, 64panel.sch]
2018-10-15 updating repo structure
    [64panel-Panel.GBL, 64panel-Panel.GBO, 64panel-Panel.GBS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]
2018-10-17 pre design review
    [LuMini_8X8.brd, LuMini_8X8.sch]
2018-10-23 updating to 4 layer
    [LuMini_8X8.brd, LuMini_8X8.sch]
2018-10-24 changing heatsinks back to ground
    [LuMini_8X8.brd, LuMini_8X8.sch]
2018-10-24 4 layer PCB note
    [LuMini_8X8.brd]
2018-12-04 updating to proper footprint
    [LuMini_8X8.GBL, LuMini_8X8.GBO, LuMini_8X8.GBS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]
2018-12-12 updating to new silk footprint for additional clarity
    [LuMini_8X8.brd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]
2018-12-13 removing problem vias
    [LuMini_8X8.brd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]
2018-12-20 updating copper to v10
    [LuMini_8X8.brd, LuMini_8X8.sch]

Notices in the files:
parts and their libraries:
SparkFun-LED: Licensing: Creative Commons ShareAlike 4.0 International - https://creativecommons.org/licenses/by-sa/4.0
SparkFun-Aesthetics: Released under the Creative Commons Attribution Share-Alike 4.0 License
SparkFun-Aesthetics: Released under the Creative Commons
